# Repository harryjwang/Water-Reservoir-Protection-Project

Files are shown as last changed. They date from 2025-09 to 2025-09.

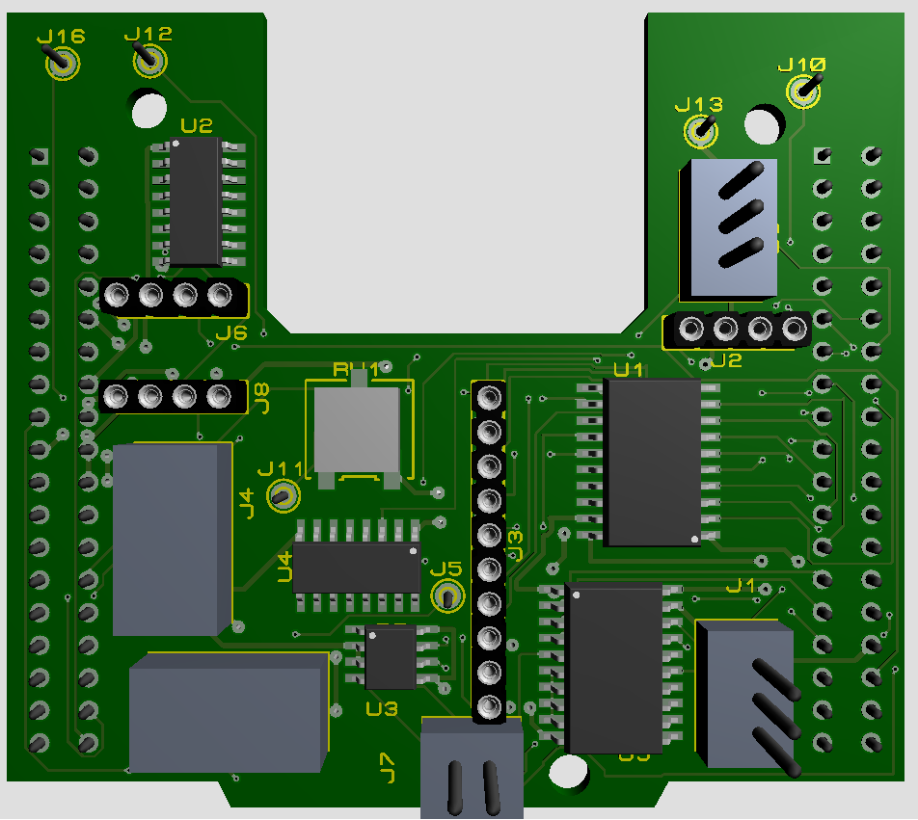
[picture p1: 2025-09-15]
Report Files/Top_View.png

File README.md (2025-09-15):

# Water-Reservoir-Protection-Project
Integrates multiple STM32 peripherals into a real-time water monitoring prototype:

- Ultrasonic sensor (HC-SR04): Determines water level.

- ADC1: Reads analog sensors (e.g., pressure/quality).

- Timers: Coordinate ultrasonic pulses and flow counting.

- UART: Reports water level + sensor readings.

- Clock: Tracks hours/minutes/seconds for timestamping.

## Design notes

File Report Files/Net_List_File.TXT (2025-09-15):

ISIS SCHEMATIC DESCRIPTION FORMAT 8.0
=====================================
Design:   ECE298_RS_ADAPTER
Doc. no.: <NONE>
Revision: <NONE>
Author:   <NONE>
Created:  11/11/2024
Modified: 12/3/2024

*PROPERTIES,0    

*MODELDEFS,0    

*PARTLIST,37   
C1,ECE298_RS_CAP_10U,100u,CODE="Digikey PCC2182TR-ND",EID=13,PACKAGE=CAPC2012X100
C2,ECE298_RS_CAP_10U,0.1u,CODE="Digikey PCC2182TR-ND",EID=7,PACKAGE=CAPC2012X100
C4,ECE298_RS_CAP_10U,100u,CODE="Digikey PCC2182TR-ND",EID=1B,PACKAGE=CAPC2012X100
C5,ECE298_RS_CAP_10U,10u,CODE="Digikey PCC2182TR-ND",EID=1C,PACKAGE=CAPC2012X100
C6,ECE298_RS_CAP_10U,0.1u,CODE="Digikey PCC2182TR-ND",EID=20,PACKAGE=CAPC2012X100
C7,ECE298_RS_CAP_10U,0.1u,CODE="Digikey PCC2182TR-ND",EID=B,PACKAGE=CAPC2012X100
C8,ECE298_RS_CAP_10U,100u,CODE="Digikey PCC2182TR-ND",EID=C,PACKAGE=CAPC2012X100
C9,ECE298_RS_CAP_10U,0.1u,CODE="Digikey PCC2182TR-ND",EID=23,PACKAGE=CAPC2012X100
C10,ECE298_RS_CAP_10U,10u,CODE="Digikey PCC2182TR-ND",EID=14,PACKAGE=CAPC2012X100
C12,ECE298_RS_CAP_10U,0.1u,CODE="Digikey PCC2182TR-ND",EID=2C,PACKAGE=CAPC2012X100
C13,ECE298_RS_CAP_10U,0.1u,CODE="Digikey PCC2182TR-ND",EID=2D,PACKAGE=CAPC2012X100
CN7,1-534236-9,1-534236-9,CODE=1-534236-9,EID=1,PACKAGE=ECE298_REVTRANS38DIL-1,SUPPLIER=TE_CONNECTIVITY
CN10,1-534236-9,1-534236-9,CODE=1-534236-9,EID=2,PACKAGE=ECE298_REVTRANS38DIL-1,SUPPLIER=TE_CONNECTIVITY
J1,ECE298_RS_3PINHDR,Servo,EID=3,PACKAGE=SIL-100-03
J2,ECE298_RS_4PINREC,"RGB LED",EID=4,PACKAGE=CONN-SIL4
J3,ECE298_RS_10PINREC,"Timer Board",EID=5,PACKAGE=CONN-SIL10
J4,ECE298_RS_BENCH_POWER,"Bench Power Supply",EID=F,PACKAGE=SIL-100-02R
J5,ECE298_TERMINAL_VIA,"Test Probe",EID=10,PACKAGE=PIN
J6,ECE298_RS_4PINREC,"RPM Sensor",EID=12,PACKAGE=CONN-SIL4
J7,ECE298_RS_2PINHDR,"Brush Motor",EID=11,PACKAGE=SIL-100-02
J8,ECE298_RS_4PINREC,"HC-SR04 Distance Sensor",EID=19,PACKAGE=CONN-SIL4
J9,ECE298_RS_3PINHDR,"USART Connector",EID=1E,PACKAGE=SIL-100-03
J10,ECE298_TERMINAL_VIA,"Test Probe",EID=25,PACKAGE=PIN
J11,ECE298_TERMINAL_VIA,"Test Probe",EID=27,PACKAGE=PIN
J12,ECE298_TERMINAL_VIA,"Test Probe",EID=29,PACKAGE=PIN
J13,ECE298_TERMINAL_VIA,"Test Probe",EID=2A,PACKAGE=PIN
J15,ECE298_RS_BENCH_POWER,"Bench Power Supply",EID=1A,PACKAGE=SIL-100-02R
J16,ECE298_TERMINAL_VIA,"Test Probe",EID=8,PACKAGE=PIN
R1,9C04021A1500JLHF3,150,CODE="Digikey 311-150JDKR-ND",EID=15,PACKAGE=RESC1005X40,PRIMTYPE=RESISTOR
R2,9C04021A1800JLHF3,80,CODE="Digikey 311-180JCT-ND",EID=16,PACKAGE=RESC1005X40,PRIMTYPE=RESISTOR
R3,9C04021A2000JLHF3,80,CODE="Digikey 311-200JCT-ND",EID=17,PACKAGE=RESC1005X40,PRIMTYPE=RESISTOR
R4,9C04021A2400JLHF3,1K,CODE="Digikey 311-240JCT-ND",EID=18,PACKAGE=RESC1005X40,PRIMTYPE=RESISTOR
RV1,ECE298_RS_POT10K,10K,CODE="Digikey 3361P-103GLFDKR-ND",EID=E,PACKAGE=TRIM_3361P,STATE=5
U1,ECE298_RS_74HCT541,ECE298_RS_74HCT541,EID=6,GND=GND,PACKAGE=SO20W,PINSWAP="1,19",VCC=+5.0V
U2,ECE298_RS_CMOS4050,ECE298_RS_CMOS4050,EID_A=9,EID_B=A,EID_C=1D,EID_D=21,EID_E=22,EID_F=24,ITFMOD=CMOS,MODFILE=40BUF,PACKAGE=SO16,VDD=+3.3V,VSS=GND
U3,ECE298_RS_L9110,"Motor Controller (L9110)",EID=D,ITFMOD=TTL,PACKAGE=SO8
U5,ECE298_RS_74HCT541,ECE298_RS_74HCT541,EID=1F,GND=GND,PACKAGE=SO20W,PINSWAP="1,19",VCC=+5.0V

*NETLIST,73   
#00076,3,CLASS=SIGNAL
J1,PS,1
U5,TS,15
J5,PS,1

#00081,2,CLASS=POWER
U3,OP,1
J7,PS,1

#00082,2,CLASS=POWER
U3,OP,4
J7,PS,2

#00090,2,CLASS=SIGNAL
R2,PS,1
U5,TS,18

#00091,3,CLASS=SIGNAL
R2,PS,2
J10,PS,1
J2,PS,1

#00093,5,CLASS=SIGNAL
R4,PS,2
U5,IP,9
U5,IP,6
U5,IP,7
U5,IP,8

#00103,2,CLASS=SIGNAL
J8,PS,3
U2,IP,3

#00109,2,CLASS=SIGNAL
J9,PS,3
U2,IP,5

#00110,2,CLASS=SIGNAL
J2,PS,2
R1,PS,2

#00112,2,CLASS=SIGNAL
J2,PS,4
R3,PS,2

#00113,2,CLASS=SIGNAL
R1,PS,1
U5,TS,17

#00114,2,CLASS=SIGNAL
R3,PS,1
U5,TS,16

#00121,3,CLASS=SIGNAL
J12,PS,1
U1,TS,18
J3,PS,1

#00133,2,CLASS=SIGNAL
U1,TS,17
J3,PS,2

#00134,2,CLASS=SIGNAL
U1,TS,16
J3,PS,3

#00135,2,CLASS=SIGNAL
U1,TS,15
J3,PS,4

#00136,2,CLASS=SIGNAL
U1,TS,14
J3,PS,5

#00137,2,CLASS=SIGNAL
U1,TS,13
J3,PS,6

#00138,2,CLASS=SIGNAL
U1,TS,12
J3,PS,7

#00139,2,CLASS=SIGNAL
U1,TS,11
J3,PS,8

PC10,2
PC10,GT
CN7,PS,1

PC11,2
PC11,GT
CN7,PS,2

PB7,2
PB7,GT
CN7,PS,21

PC12,2
PC12,GT
CN7,PS,3

PA1,2
PA1,GT
CN7,PS,30

PA4,2
PA4,GT
CN7,PS,32

PB0,2
PB0,GT
CN7,PS,34

PC2,2
PC2,GT
CN7,PS,35

PC3,2
PC3,GT
CN7,PS,37

PC9,2
PC9,GT
CN10,PS,1

PB12,2
PB12,GT
CN10,PS,16

PC8,2
PC8,GT
CN10,PS,2

PB2,2
PB2,GT
CN10,PS,22

PB1,2
PB1,GT
CN10,PS,24

PB15,2
PB15,GT
CN10,PS,26

PB8,2
PB8,GT
CN10,PS,3

PA10,2
PA10,GT
CN10,PS,33

PC6,2
PC6,GT
CN10,PS,4

PB9,2
PB9,GT
CN10,PS,5

PC5,2
PC5,GT
CN10,PS,6

PA13,2
PA13,GT
CN7,PS,13

PA14,2
PA14,GT
CN7,PS,15

PC13,2
PC13,GT
CN7,PS,23

PB11,2
PB11,GT
CN10,PS,18

PA2,2
PA2,GT
CN10,PS,35

PA3,2
PA3,GT
CN10,PS,37

MOTOR_CONTROL_PWM_1 (PB_14),3,CLASS=SIGNAL
MOTOR_CONTROL_PWM_1 (PB_14),GT
U3,IP,6
CN10,PS,28

MOTOR_CONTROL_PWM_2 (PB_13),3,CLASS=SIGNAL
MOTOR_CONTROL_PWM_2 (PB_13),GT
U3,IP,7
CN10,PS,30

POTENTIOMETER_ADC (PA_0),4,CLASS=SIGNAL
POTENTIOMETER_ADC (PA_0),GT
RV1,PS,3
J11,PS,1
CN7,PS,28

RPM_D0_PIN (PC_4),3,CLASS=SIGNAL
RPM_D0_PIN (PC_4),GT
J6,PS,3
CN10,PS,34

DISTANCE_TRIG_INPUT (PC_1),3,CLASS=SIGNAL
DISTANCE_TRIG_INPUT (PC_1),GT
J8,PS,2
CN7,PS,36

NUCLEO_TO_USART (PA_11),3,CLASS=SIGNAL
NUCLEO_TO_USART (PA_11),GT
J9,PS,2
CN10,PS,14

USART_TO_NUCLEO (PA_12),3,CLASS=SIGNAL
USART_TO_NUCLEO (PA_12),GT
U2,OP,4
CN10,PS,12

SERVO_PWM_PIN (PA_15),3,CLASS=SIGNAL
SERVO_PWM_PIN (PA_15),GT
U5,IP,5
CN7,PS,17

DISTANCE_ECHO_OUTPUT (PC_0),4,CLASS=SIGNAL
DISTANCE_ECHO_OUTPUT (PC_0),GT
J16,PS,1
U2,OP,2
CN7,PS,38

SEVEN_SEG_D0_IN (PA_5),3,CLASS=SIGNAL
SEVEN_SEG_D0_IN (PA_5),GT
U1,IP,2
CN10,PS,11

SEVEN_SEG_D1_IN (PA_6),3,CLASS=SIGNAL
SEVEN_SEG_D1_IN (PA_6),GT
U1,IP,3
CN10,PS,13

SEVEN_SEG_D2_IN (PA_7),3,CLASS=SIGNAL
SEVEN_SEG_D2_IN (PA_7),GT
U1,IP,4
CN10,PS,15

SEVEN_SEG_D3_IN (PB_6),3,CLASS=SIGNAL
SEVEN_SEG_D3_IN (PB_6),GT
U1,IP,5
CN10,PS,17

SEVEN_SEG_D4_IN (PC_7),3,CLASS=SIGNAL
SEVEN_SEG_D4_IN (PC_7),GT
U1,IP,6
CN10,PS,19

SEVEN_SEG_D5_IN (PA_9),3,CLASS=SIGNAL
SEVEN_SEG_D5_IN (PA_9),GT
U1,IP,7
CN10,PS,21

SEVEN_SEG_D6_IN (PA_8),3,CLASS=SIGNAL
SEVEN_SEG_D6_IN (PA_8),GT
U1,IP,8
CN10,PS,23

SEVEN_SEG_D7_IN (PB_10),3,CLASS=SIGNAL
SEVEN_SEG_D7_IN (PB_10),GT
U1,IP,9
CN10,PS,25

RED_LED_PIN (PB_4),3,CLASS=SIGNAL
RED_LED_PIN (PB_4),GT
U5,IP,2
CN10,PS,27

GREEN_LED_PIN (PB_5),3,CLASS=SIGNAL
GREEN_LED_PIN (PB_5),GT
U5,IP,3
CN10,PS,29

BLUE_LED_PIN (PB_3),3,CLASS=SIGNAL
BLUE_LED_PIN (PB_3),GT
U5,IP,4
CN10,PS,31

{NC},31,CLASS=SIGNAL
U2,PS,13
U2,PS,16
U2,OP,15
U2,OP,12
U2,OP,10
U2,OP,6
U5,TS,11
U5,TS,12
U5,TS,13
U5,TS,14
J6,PS,4
CN7,PS,14
CN10,PS,8
CN10,PS,7
CN10,PS,38
CN10,PS,36
CN10,PS,10
CN7,PS,9
CN7,PS,7
CN7,PS,6
CN7,PS,5
CN7,PS,4
CN7,PS,33
CN7,PS,31
CN7,PS,29
CN7,PS,27
CN7,PS,26
CN7,PS,25
CN7,PS,24
CN7,PS,11
CN7,PS,10

+3.3V,11,CLASS=POWER
+3.3V,PR
VCC,LBL
U2,PP,1
C7,PS,1
C2,PS,1
C4,PS,1
J6,PS,1
C1,PS,1
RV1,PS,2
CN7,PS,16
CN7,PS,12

+5.0V,9,CLASS=POWER
+5.0V,PR
U5,PP,20
C8,PS,1
J3,PS,9
C13,PS,1
C12,PS,1
U1,PP,20
J8,PS,1
CN7,PS,18

+5.0V_EXT,2,CLASS=POWER
+5.0V_EXT,PR
J1,PS,2

+5V_EXT,3,CLASS=POWER
+5V_EXT,PR
J15,PS,1
C10,PS,1

+6V_EXT,7,CLASS=POWER
+6V_EXT,PR
C9,PS,1
C6,PS,1
J4,PS,1
C5,PS,1
U3,PP,2
U3,PP,3

GND,43,CLASS=POWER
GND,PR
U2,PP,8
U2,IP,9
U2,IP,11
U2,IP,7
U2,IP,14
U5,PP,10
J15,PS,2
C10,PS,2
C8,PS,2
J13,PS,1
C7,PS,2
C2,PS,2
C6,PS,2
C13,PS,2
C12,PS,2
U1,PP,10
C9,PS,2
U1,IP,1
U1,IP,19
J2,PS,3
J9,PS,1
J3,PS,10
J8,PS,4
J6,PS,2
J4,PS,2
C5,PS,2
R4,PS,1
U5,IP,1
U5,IP,19
C1,PS,2
RV1,PS,1
U3,PP,5
U3,PP,8
J1,PS,3
CN10,PS,9
CN10,PS,32
CN10,PS,20
C4,PS,2
CN7,PS,8
CN7,PS,22
CN7,PS,20
CN7,PS,19

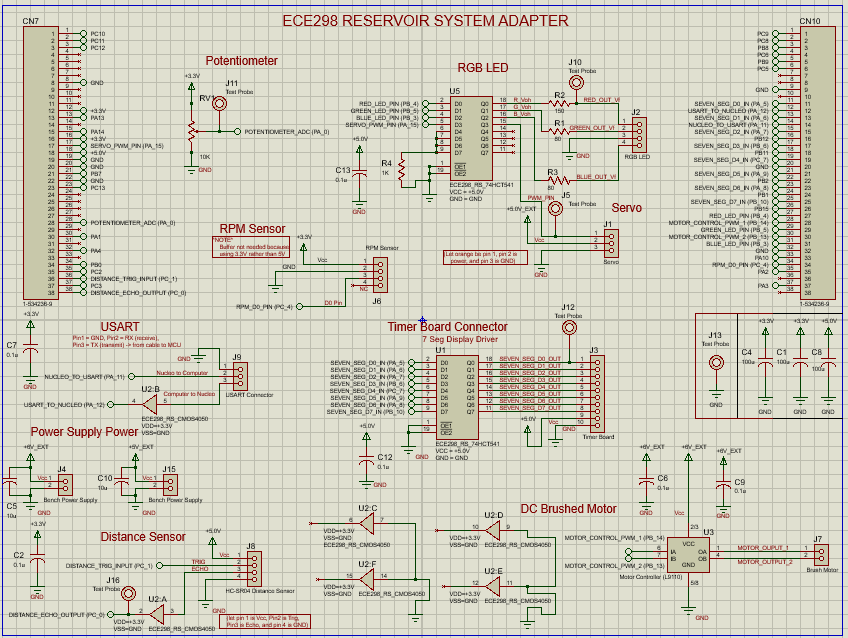
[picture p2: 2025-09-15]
Report Files/Final Schematic.PNG

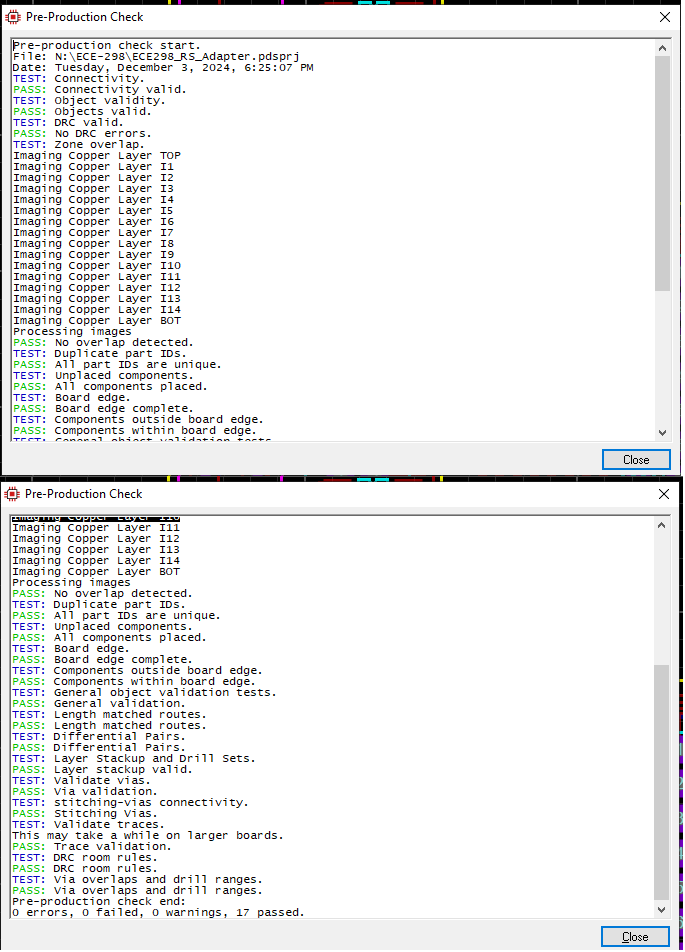
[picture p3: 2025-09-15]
Report Files/Pre_Production_Checklist.png

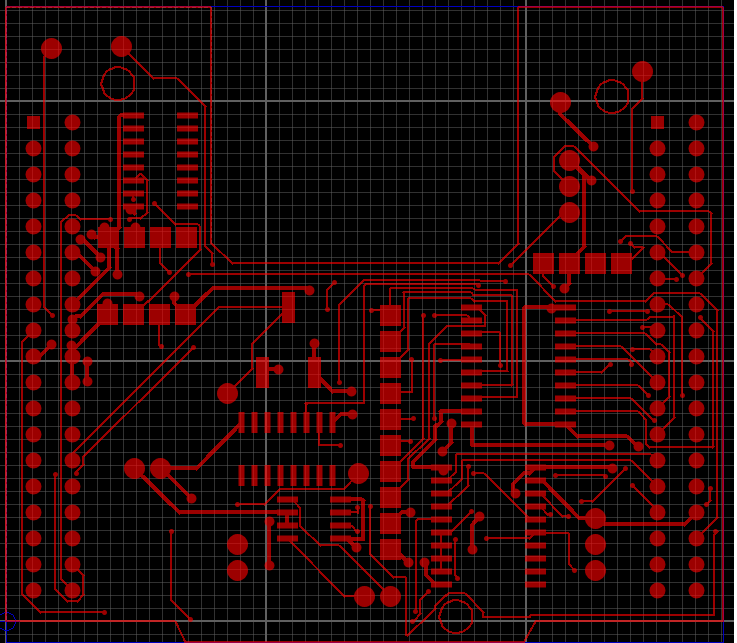
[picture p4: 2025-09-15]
Report Files/Top_Copper_Layer.png

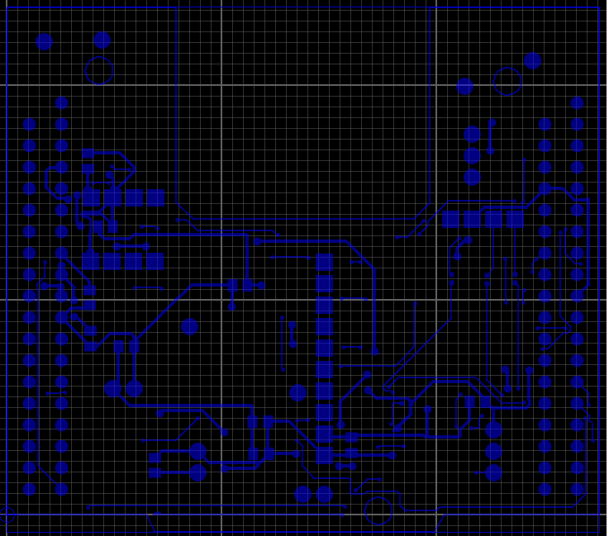
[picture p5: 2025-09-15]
Report Files/Bottom_Copper_Layer.png

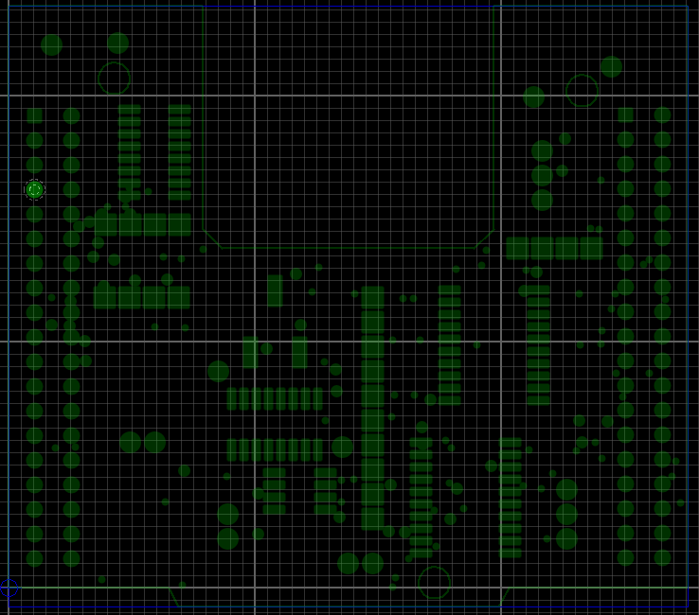
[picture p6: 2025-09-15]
Report Files/Top_Resistor_Layer.png

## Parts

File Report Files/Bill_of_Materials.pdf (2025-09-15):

## Bill Of Materials for ECE298_RS_ADAPTER

Design Title | ECE298_RS_ADAPTER

### Author Document Number Revision

Design Created | Monday, November 11, 2024
Design Last Modified Monday, November 11, 2024

### Total Parts In Design 38

0 Modules
Quantity | References | Value
Sub-totals:
11 Capacitors
Quantity | References | Value
3 | C1,C4,C8 | 100u
6 | C2,C6-C7,C9,C12-C13 | 0.1u
2 | C5,C10 | 10u
Sub-totals:
4 Resistors
Quantity | References | Value
1 | R1 | 150
2 | R2-R3 | 80
1 | R4 | 1K
Sub-totals:
5 Integrated Circuits
Quantity | References | Value
2 | U1,U5 | ECE298_RS_74HCT541
2 | U2,U4 | ECE298_RS_CMOS4050
1 | U3 | Motor Controller (L9110)
Sub-totals:
0 Transistors
Quantity | References | Value
Sub-totals:
0 Diodes
Quantity | References | Value
Sub-totals:
18 Miscellaneous
Quantity | References | Value
2 | CN7,CN10 | 1-534236-9
1 | J1 | Servo
1 | J2 | RGB LED
1 | J3 | Timer Board
2 | J4,J15 | Bench Power Supply
6 | J5,J10-J13,J16 | Test Probe
1 | J6 | RPM Sensor
1 | J7 | Brush Motor
1 | J8 | HC-SR04 Distance Sensor
1 | J9 | USARTConnector
1 | RV1 | 10K
Sub-totals:

Totals:

| | Tuesday, December 3, 2024 6:30:23 PM

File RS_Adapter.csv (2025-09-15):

Part ID | Value | Package | Stock Code | Layer | Rotation | X | Y
CN7 | 1-534236-9 | ECE298_REVTRANS38DIL-1 | 1-534236-9 | BOT | 0 | 177.362 | 1019.69
CN10 | 1-534236-9 | ECE298_REVTRANS38DIL-1 | 1-534236-9 | BOT | 0 | 2577.36 | 1021.26
J2 | RGB LED | CONN-SIL4 |  | TOP | 180 | 2213.78 | 1377.95
J3 | Timer Board | CONN-SIL10 |  | TOP | 270 | 1476.38 | 729.528
J4 | Bench Power Supply | SIL-100-02R |  | TOP | 0 | 542.126 | 590.551
J6 | RPM Sensor | CONN-SIL4 |  | TOP | 0 | 542.126 | 1476.38
J8 | HC-SR04 Distance Sensor | CONN-SIL4 |  | TOP | 180 | 538.976 | 1181.1
J9 | USART Connector | SIL-100-03 |  | TOP | 270 | 2165.35 | 1674.8
J7 | Brush Motor | SIL-100-02 |  | TOP | 180 | 1426.38 | 98.4252
J15 | Bench Power Supply | SIL-100-02R |  | TOP | 90 | 887.402 | 246.85
U1 | ECE298_RS_74HCT541 | SO20W |  | TOP | -180 | 1968.5 | 984.252
U2 | ECE298_RS_CMOS4050 | SO16 |  | TOP | 0 | 590.551 | 1771.65
U3 | Motor Controller (L9110) | SO8 |  | TOP | 0 | 1181.1 | 393.701
U4 | ECE298_RS_CMOS4050 | SO16 |  | TOP | 270 | 1078.6 | 663.976
U5 | ECE298_RS_74HCT541 | SO20W |  | TOP | 0 | 1853.23 | 367.126
J1 | Servo | SIL-100-03 |  | TOP | 90 | 2263.78 | 296.85
RV1 | 10K | TRIM_3361P | Digikey 3361P-103GLFDKR-ND | TOP | 0 | 1082.68 | 1082.68
R1 | 150 | RESC1005X40 | Digikey 311-150JDKR-ND | BOT | -90 | 2232.28 | 1098.43
R2 | 80 | RESC1005X40 | Digikey 311-180JCT-ND | BOT | -90 | 2362.2 | 1102.36
R3 | 80 | RESC1005X40 | Digikey 311-200JCT-ND | BOT | -90 | 2066.93 | 1102.36
C5 | 10u | CAPC2012X100 | Digikey PCC2182TR-ND | BOT | 180 | 555.118 | 787.402
C10 | 10u | CAPC2012X100 | Digikey PCC2182TR-ND | BOT | -90 | 688.976 | 232.283
C2 | 0.1u | CAPC2012X100 | Digikey PCC2182TR-ND | BOT | 180 | 456.693 | 1342.52
C1 | 100u | CAPC2012X100 | Digikey PCC2182TR-ND | BOT | 270 | 374.016 | 1649.61
R4 | 1K | RESC1005X40 | Digikey 311-240JCT-ND | BOT | 0 | 1858.27 | 519.685
C9 | 0.1u | CAPC2012X100 | Digikey PCC2182TR-ND | BOT | -180 | 1177.17 | 437.008
C6 | 0.1u | CAPC2012X100 | Digikey PCC2182TR-ND | BOT | 180 | 1181.1 | 287.402
C7 | 0.1u | CAPC2012X100 | Digikey PCC2182TR-ND | BOT | 0 | 1082.68 | 1070.87
C4 | 100u | CAPC2012X100 | Digikey PCC2182TR-ND | BOT | 90 | 381.89 | 1011.81
C8 | 100u | CAPC2012X100 | Digikey PCC2182TR-ND | BOT | 90 | 385.827 | 822.835
C12 | 0.1u | CAPC2012X100 | Digikey PCC2182TR-ND | BOT | 90 | 1602.36 | 326.772
C13 | 0.1u | CAPC2012X100 | Digikey PCC2182TR-ND | BOT | 180 | 2188.98 | 527.559
J5 | Test Probe | PIN |  | TOP | 0 | 1354.33 | 570.866
J11 | Test Probe | PIN |  | TOP | 0 | 850.394 | 877.953
J13 | Test Probe | PIN |  | TOP | 0 | 2129.92 | 1996.06
J10 | Test Probe | PIN |  | TOP | 0 | 2444.88 | 2118.11
J12 | Test Probe | PIN |  | TOP | 0 | 440.945 | 2212.6
J16 | Test Probe | PIN |  | TOP | 0 | 173.228 | 2204.72

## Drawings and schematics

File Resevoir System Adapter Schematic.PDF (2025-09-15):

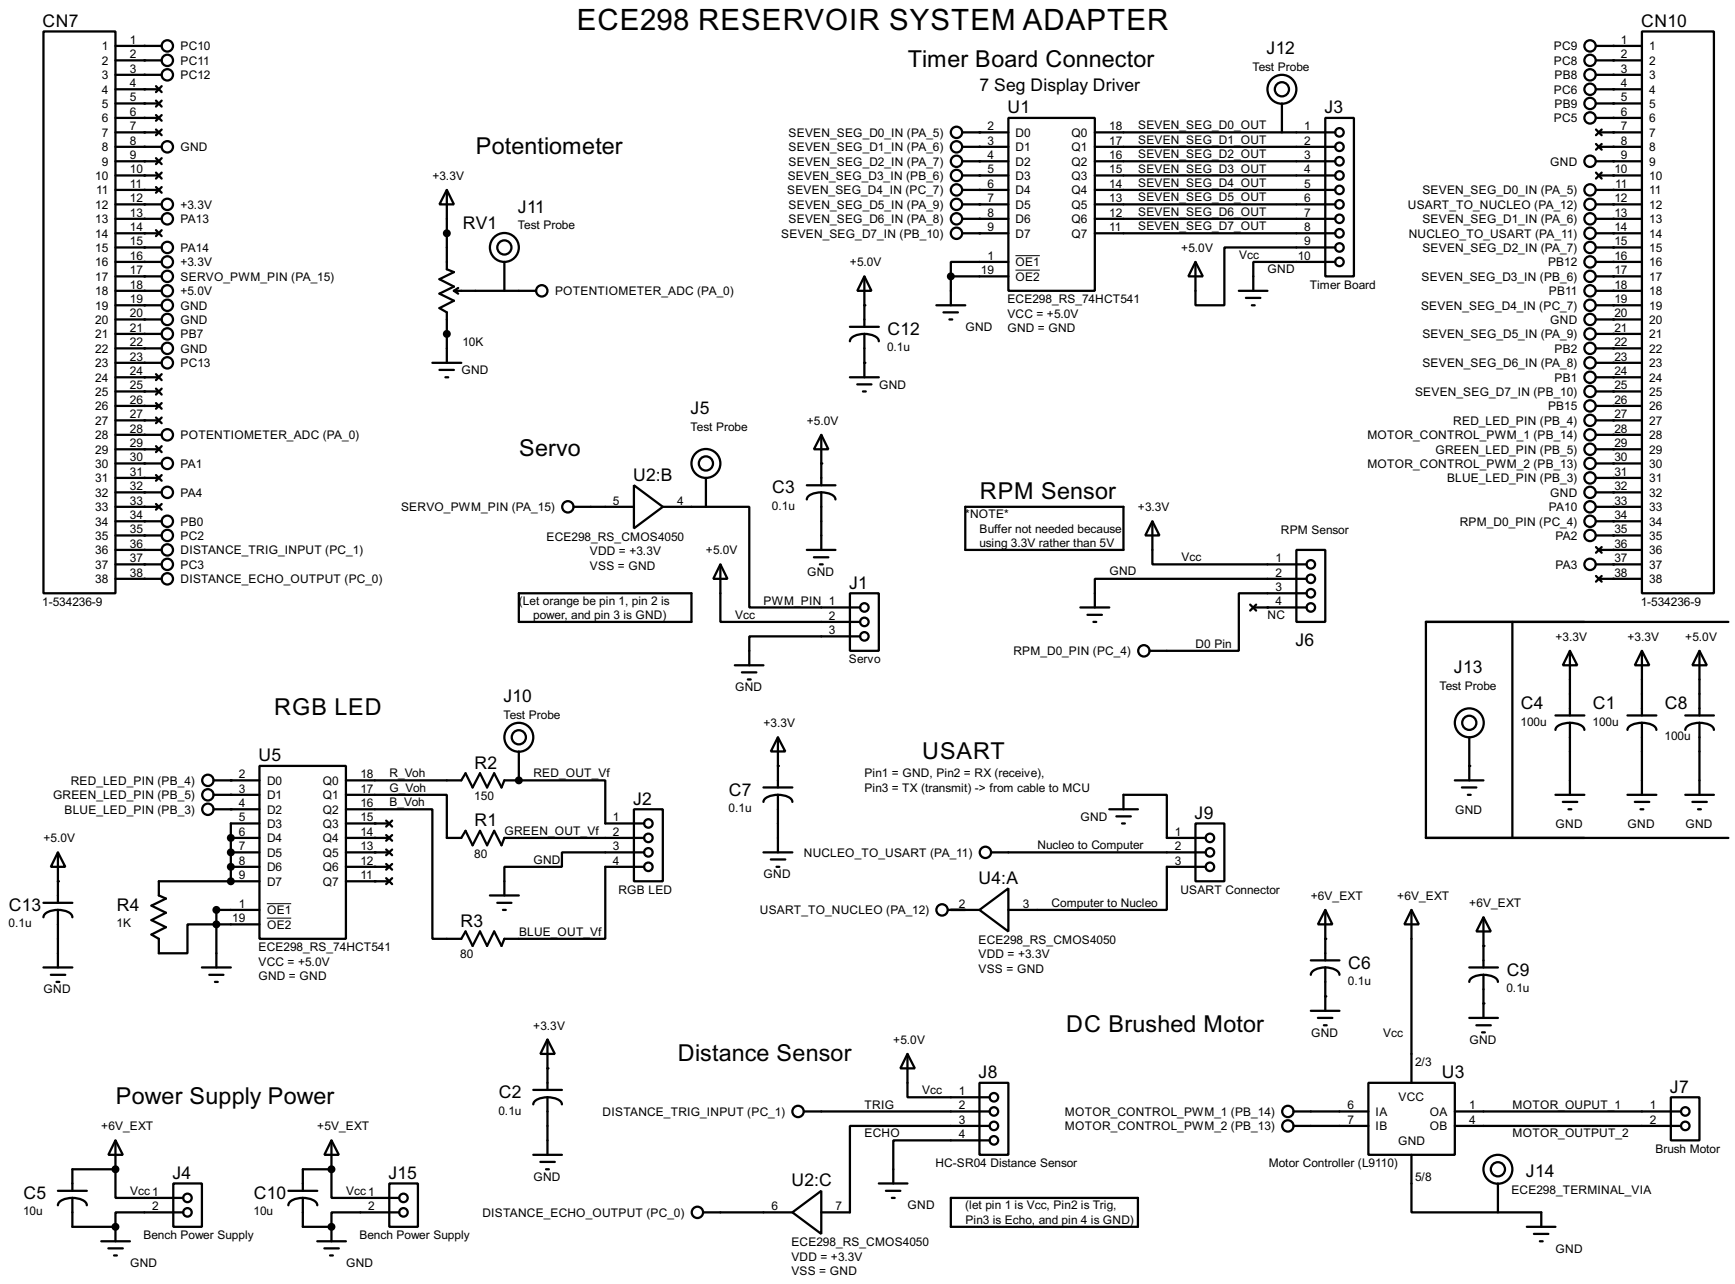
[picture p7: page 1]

*NOTE* Buffer not needed because

(Let orange be pin 1, pin 2 is
power, and pin 3 is GND)

Pin3 = TX (transmit) -> from cable to MCU

(let pin 1 is Vcc, Pin2 is Trig,
Pin3 is Echo, and pin 4 is GND)

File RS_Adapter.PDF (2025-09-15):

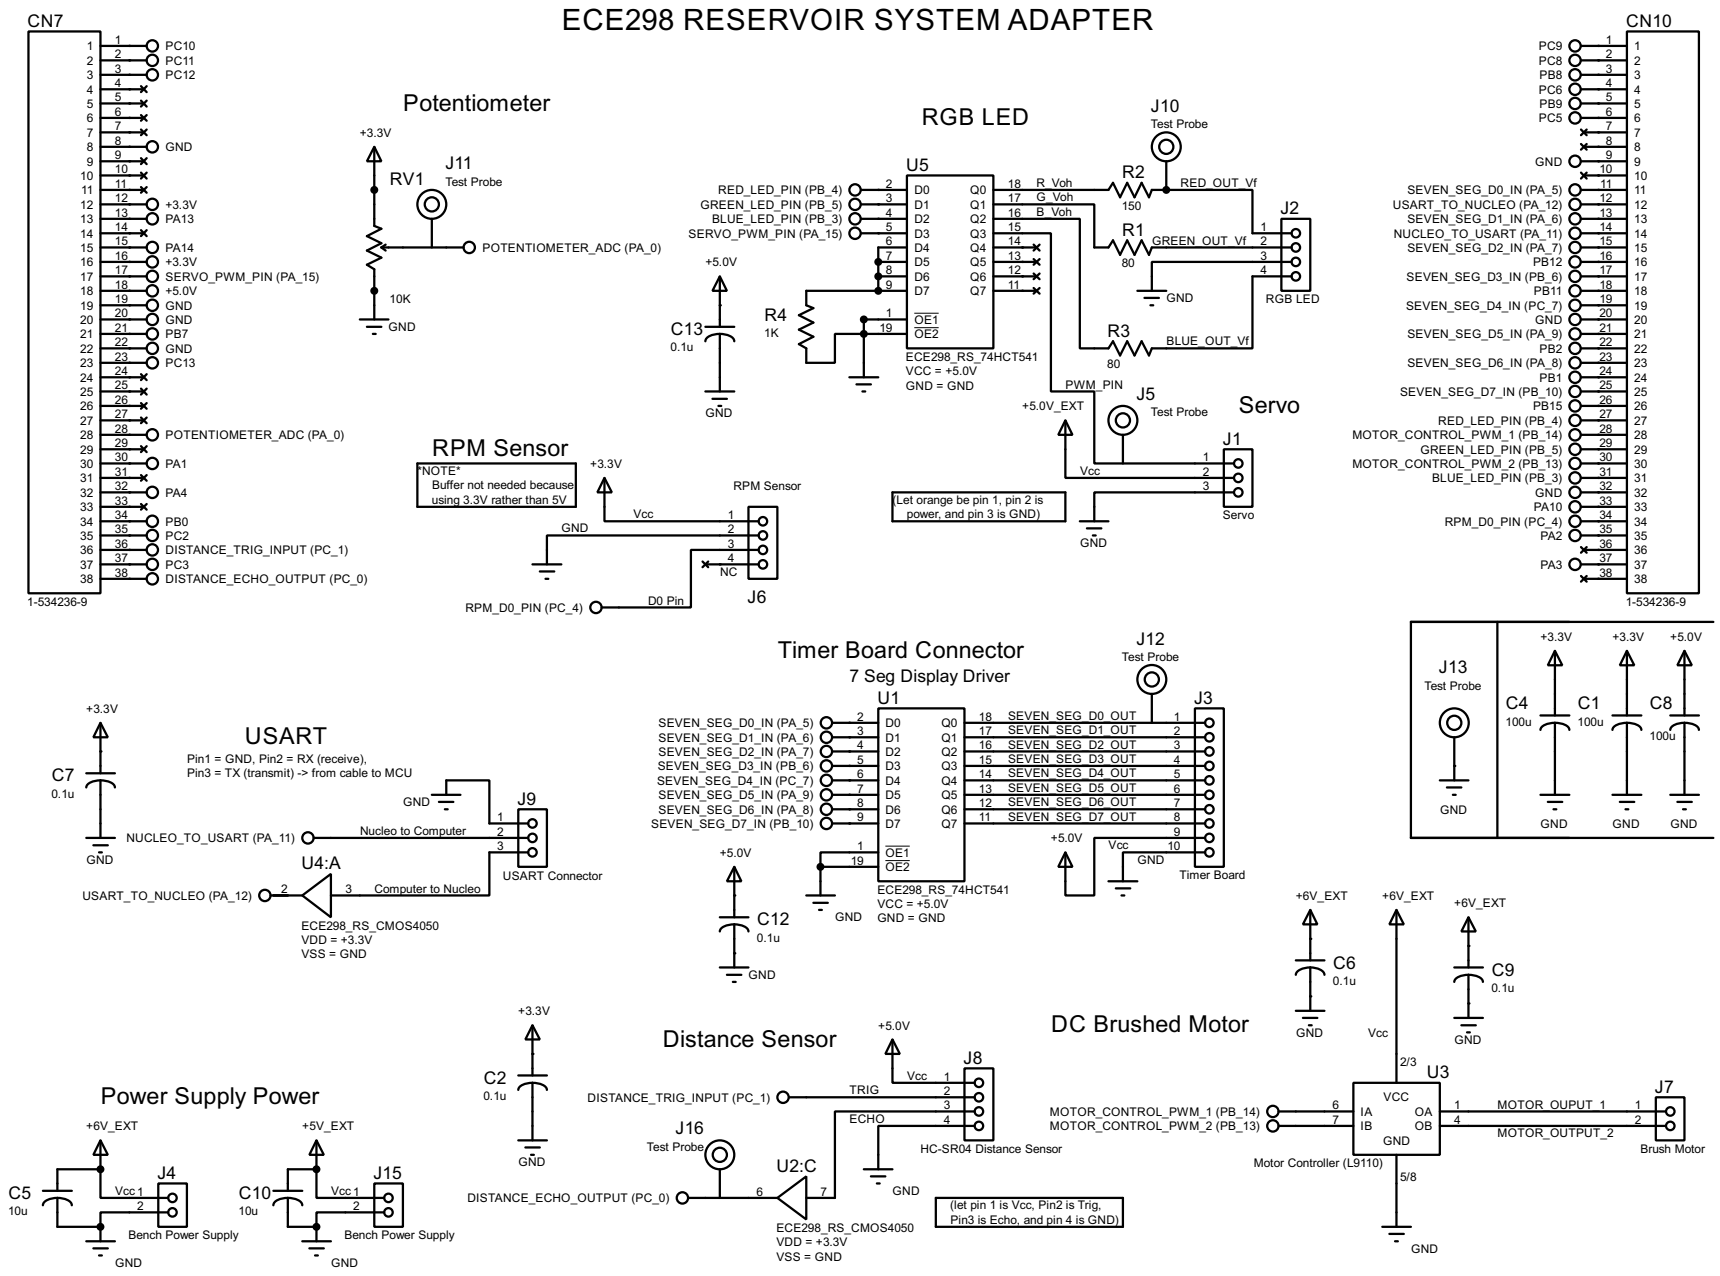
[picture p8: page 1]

*NOTE* Buffer not needed because

(Let orange be pin 1, pin 2 is
power, and pin 3 is GND)

Pin1 = GND, Pin2 = RX (receive),
Pin3 = TX (transmit) -> from cable to MCU

(let pin 1 is Vcc, Pin2 is Trig,
Pin3 is Echo, and pin 4 is GND)

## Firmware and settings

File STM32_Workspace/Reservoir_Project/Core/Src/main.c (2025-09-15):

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
/* Includes ------------------------------------------------------------------*/
#include "main.h"
#include <string.h>
#include <stdio.h>
uint8_t txd_message_buffer[64] = {0};
uint8_t rpm_tick_count = 0;
ADC_HandleTypeDef hadc1;

TIM_HandleTypeDef htim1;
TIM_HandleTypeDef htim3;

UART_HandleTypeDef huart2;
UART_HandleTypeDef huart6;

/* USER CODE BEGIN PV */
uint8_t wall_clock_hr_update_flag = 0;
volatile uint8_t clock_hours = 0;
volatile uint8_t clock_mins = 0;
volatile uint8_t clock_secs = 0;
volatile uint8_t distance = 0;
/* USER CODE END PV */

void SystemClock_Config(void);
static void MX_GPIO_Init(void);
static void MX_USART2_UART_Init(void);
static void MX_ADC1_Init(void);
static void MX_TIM1_Init(void);
static void MX_TIM3_Init(void);
static void MX_USART6_UART_Init(void);
/* USER CODE BEGIN 0 */
volatile uint8_t hcsr04_Rx_flag = 0;
volatile uint32_t first_edge = 0;
volatile uint32_t time_edge1 = 0;
volatile uint32_t time_edge2 = 0;
volatile uint32_t time_diff = 0;

void ADC_Select_CH(int CH)
{
ADC_ChannelConfTypeDef sConfig = {0};
switch(CH)
{
case 0:
sConfig.Channel = ADC_CHANNEL_0;
sConfig.Rank = 1;
if (HAL_ADC_ConfigChannel(&hadc1, &sConfig) != HAL_OK)
{
Error_Handler();
}
break;
case 1:
sConfig.Channel = ADC_CHANNEL_1;
sConfig.Rank = 1;
if (HAL_ADC_ConfigChannel(&hadc1, &sConfig) != HAL_OK)
{
Error_Handler();
}
break;
case 2:
sConfig.Channel = ADC_CHANNEL_2;
sConfig.Rank = 1;
if (HAL_ADC_ConfigChannel(&hadc1, &sConfig) != HAL_OK)
{
Error_Handler();
}
break;
case 3:
sConfig.Channel = ADC_CHANNEL_3;
sConfig.Rank = 1;
if (HAL_ADC_ConfigChannel(&hadc1, &sConfig) != HAL_OK)
{
Error_Handler();
}
break;
case 4:
sConfig.Channel = ADC_CHANNEL_4;
sConfig.Rank = 1;
if (HAL_ADC_ConfigChannel(&hadc1, &sConfig) != HAL_OK)
{
Error_Handler();
}
break;
case 5:
sConfig.Channel = ADC_CHANNEL_5;
sConfig.Rank = 1;
if (HAL_ADC_ConfigChannel(&hadc1, &sConfig) != HAL_OK)
{
Error_Handler();
}
break;
case 6:
sConfig.Channel = ADC_CHANNEL_6;
sConfig.Rank = 1;
if (HAL_ADC_ConfigChannel(&hadc1, &sConfig) != HAL_OK)
{
Error_Handler();
}
break;
case 7:
sConfig.Channel = ADC_CHANNEL_7;
sConfig.Rank = 1;
if (HAL_ADC_ConfigChannel(&hadc1, &sConfig) != HAL_OK)
{
Error_Handler();
}
break;
case 8:
sConfig.Channel = ADC_CHANNEL_8;
sConfig.Rank = 1;
if (HAL_ADC_ConfigChannel(&hadc1, &sConfig) != HAL_OK)
{
Error_Handler();
}
break;
case 9:
sConfig.Channel = ADC_CHANNEL_9;
sConfig.Rank = 1;
if (HAL_ADC_ConfigChannel(&hadc1, &sConfig) != HAL_OK)
{
Error_Handler();
}
break;
case 10:
sConfig.Channel = ADC_CHANNEL_10;
sConfig.Rank = 1;
if (HAL_ADC_ConfigChannel(&hadc1, &sConfig) != HAL_OK)
{
Error_Handler();
}
break;
case 11:
sConfig.Channel = ADC_CHANNEL_11;
sConfig.Rank = 1;
if (HAL_ADC_ConfigChannel(&hadc1, &sConfig) != HAL_OK)
{
Error_Handler();
}
break;
case 12:
sConfig.Channel = ADC_CHANNEL_12;
sConfig.Rank = 1;
if (HAL_ADC_ConfigChannel(&hadc1, &sConfig) != HAL_OK)
{
Error_Handler();
}
break;
case 13:
sConfig.Channel = ADC_CHANNEL_13;
sConfig.Rank = 1;
if (HAL_ADC_ConfigChannel(&hadc1, &sConfig) != HAL_OK)
{
Error_Handler();
}
break;
case 14:
sConfig.Channel = ADC_CHANNEL_14;
sConfig.Rank = 1;
if (HAL_ADC_ConfigChannel(&hadc1, &sConfig) != HAL_OK)
{
Error_Handler();
}
break;
case 15:
sConfig.Channel = ADC_CHANNEL_15;
sConfig.Rank = 1;
if (HAL_ADC_ConfigChannel(&hadc1, &sConfig) != HAL_OK)
{
Error_Handler();
}
break;
}
}
/* USER CODE END 0 */

/**
  * @brief  The application entry point.
  * @retval int
  */
int main(void)
{

  /* USER CODE BEGIN 1 */

	//distance sensor pulse sending
	void HCSR04_TRIG_PULSE(void){
		HAL_GPIO_WritePin(GPIOC, TRIG_PIN_Pin, GPIO_PIN_SET);
		for(int j=0; j!=48; j= j+1){};
		HAL_GPIO_WritePin(GPIOC, TRIG_PIN_Pin, GPIO_PIN_RESET);
		HAL_Delay(30);
	}

	// printing digits A and B
	void DIGITS_Display(uint8_t DIGIT_A, uint8_t DIGIT_B)
		{
			 uint8_t DIGITA_VAL = 0x0F & DIGIT_A; //mask off higher4 bits
			 int Abit0 = (DIGITA_VAL ) & 1;  	// extract Abit0 of the 4-bit value
			 int Abit1 = (DIGITA_VAL >> 1) & 1;  // extract Abit1 of the 4-bit value
			 int Abit2 = (DIGITA_VAL >> 2) & 1;  // extract Abit2 of the 4-bit value
			 int Abit3 = (DIGITA_VAL >> 3) & 1;  // extract Abit3 of the 4-bit value

			 uint8_t DIGITB_VAL = 0x0F & DIGIT_B; //mask off higher4 bits
			 int Bbit0 = (DIGITB_VAL ) & 1;  	// extract Bbit0 of the 4-bit value
			 int Bbit1 = (DIGITB_VAL >> 1) & 1;  // extract Bbit1 of the 4-bit value
			 int Bbit2 = (DIGITB_VAL >> 2) & 1;  // extract Bbit2 of the 4-bit value
			 int Bbit3 = (DIGITB_VAL >> 3) & 1;  // extract Bbit3 of the 4-bit value

			 if (Abit0 == (0))
			 {
				 HAL_GPIO_WritePin(GPIOB, DIGIT_A0_Pin, GPIO_PIN_RESET);
			 }
			 else
			 {
				 HAL_GPIO_WritePin(GPIOB, DIGIT_A0_Pin, GPIO_PIN_SET);
			 }
			 if (Abit1 == (0))
			 {
				 HAL_GPIO_WritePin(GPIOA, DIGIT_A1_Pin, GPIO_PIN_RESET);
			 }
			 else
			 {
				 HAL_GPIO_WritePin(GPIOA, DIGIT_A1_Pin, GPIO_PIN_SET);
			 }
			 if (Abit2 == (0))
			 {
				 HAL_GPIO_WritePin(GPIOA, DIGIT_A2_Pin, GPIO_PIN_RESET);
			 }
			 else
			 {
				 HAL_GPIO_WritePin(GPIOA, DIGIT_A2_Pin, GPIO_PIN_SET);
			 }
			 if (Abit3 == (0))
			 {
				 HAL_GPIO_WritePin(GPIOA, DIGIT_A3_Pin, GPIO_PIN_RESET);
			 }
			 else
			 {
				 HAL_GPIO_WritePin(GPIOA, DIGIT_A3_Pin, GPIO_PIN_SET);
			 }
			 if (Bbit0 == (0))
			 {
				 HAL_GPIO_WritePin(GPIOB, DIGIT_B0_Pin, GPIO_PIN_RESET);
			 }
			 else
			 {
				 HAL_GPIO_WritePin(GPIOB, DIGIT_B0_Pin, GPIO_PIN_SET);
			 }
			 if (Bbit1 == (0))
			 {
				 HAL_GPIO_WritePin(GPIOB, DIGIT_B1_Pin, GPIO_PIN_RESET);
			 }
			 else
			 {
				 HAL_GPIO_WritePin(GPIOB, DIGIT_B1_Pin, GPIO_PIN_SET);

			 }
			 if (Bbit2 == (0))
			 {
				 HAL_GPIO_WritePin(GPIOC, DIGIT_B2_Pin, GPIO_PIN_RESET);
			 }
			 else
			 {
				 HAL_GPIO_WritePin(GPIOC, DIGIT_B2_Pin, GPIO_PIN_SET);
			 }
			 if (Bbit3 == (0))
			 {
				 HAL_GPIO_WritePin(GPIOC, DIGIT_B3_Pin, GPIO_PIN_RESET);
			 }
			 else
			 {
				 HAL_GPIO_WritePin(GPIOC, DIGIT_B3_Pin, GPIO_PIN_SET);
			 }
		}


  /* USER CODE END 1 */

  /* MCU Configuration--------------------------------------------------------*/

  /* Reset of all peripherals, Initializes the Flash interface and the Systick. */
  HAL_Init();

  /* Configure the system clock */
  SystemClock_Config();

  /* USER CODE BEGIN SysInit */
  int TIM1_Ch1_DCVAL = 500;
  int TIM1_CH1_STEP = 20;
  /* USER CODE END SysInit */

  /* Initialize all configured peripherals */
  MX_GPIO_Init();
  MX_USART2_UART_Init();
  MX_ADC1_Init();
  MX_TIM1_Init();
  MX_TIM3_Init();
  MX_USART6_UART_Init();
  /* USER CODE BEGIN 2 */
  HAL_TIM_Base_Start(&htim1);
  HAL_TIM_PWM_Start(&htim1,TIM_CHANNEL_1);

  TIM1->PSC = 16-1;
  TIM1->ARR = 20000-1;
  TIM1->CCR1 = 00;

  clock_hours = 0;

//  uint8_t timer_ones = timer % 10;
//  uint8_t timer_tens = (timer - timer_ones) / 10;  // separate out digits A and B

  /* USER CODE END 2 */

  /* Infinite loop */
  /* USER CODE BEGIN WHILE */
//  HCSR04_TRIG_PULSE();
  TIM1->CCR1 = 2500;
  HAL_GPIO_WritePin(GPIOA, LD2_Pin, GPIO_PIN_RESET);

 // * SETUP CODE
  // Array to store inputs
    uint8_t setupInputs[17];
    char buffer[2] = {0};

    // Prompt and collect inputs
    sprintf((char*)txd_message_buffer, "\r SETUP MODE \n\n");
    HAL_UART_Transmit(&huart6, txd_message_buffer, strlen((char*)txd_message_buffer), HAL_MAX_DELAY);
    HAL_Delay(500);

    sprintf((char*)txd_message_buffer, "\r Enter SETUP Params \n\n");
    HAL_UART_Transmit(&huart6, txd_message_buffer, strlen((char*)txd_message_buffer), HAL_MAX_DELAY);

    sprintf((char*)txd_message_buffer, "\r\n Enter FIRST PIPELINE CHOICE FOR CONNECTION (0 for DEMO): ");
    HAL_UART_Transmit(&huart6, txd_message_buffer, strlen((char*)txd_message_buffer), HAL_MAX_DELAY);
    HAL_UART_Receive(&huart6, (uint8_t *)buffer, 1, HAL_MAX_DELAY);
    HAL_UART_Transmit(&huart6, (uint8_t *)buffer, 1, HAL_MAX_DELAY);
    setupInputs[0] = atoi(buffer);

    sprintf((char*)txd_message_buffer, "\r\n Enter FIRST PIPELINE CHOICE FOR MOTOR PWM (0 for DEMO): ");
    HAL_UART_Transmit(&huart6, txd_message_buffer, strlen((char*)txd_message_buffer), HAL_MAX_DELAY);
    HAL_UART_Receive(&huart6, (uint8_t *)buffer, 1, HAL_MAX_DELAY);
    HAL_UART_Transmit(&huart6, (uint8_t *)buffer, 1, HAL_MAX_DELAY);
    setupInputs[1] = atoi(buffer);

    sprintf((char*)txd_message_buffer, "\r\n Enter SECOND ZONE CHOICE FOR CONNECTION (1-3): ");
    HAL_UART_Transmit(&huart6, txd_message_buffer, strlen((char*)txd_message_buffer), HAL_MAX_DELAY);
    HAL_UART_Receive(&huart6, (uint8_t *)buffer, 1, HAL_MAX_DELAY);
    HAL_UART_Transmit(&huart6, (uint8_t *)buffer, 1, HAL_MAX_DELAY);
    setupInputs[2] = atoi(buffer);

    sprintf((char*)txd_message_buffer, "\r\n Enter SECOND ZONE CHOICE FOR MOTOR PWM (1-3): ");
    HAL_UART_Transmit(&huart6, txd_message_buffer, strlen((char*)txd_message_buffer), HAL_MAX_DELAY);
    HAL_UART_Receive(&huart6, (uint8_t *)buffer, 1, HAL_MAX_DELAY);
    HAL_UART_Transmit(&huart6, (uint8_t *)buffer, 1, HAL_MAX_DELAY);
    setupInputs[3] = atoi(buffer);

    sprintf((char*)txd_message_buffer, "\r\n Enter THIRD ZONE CHOICE FOR CONNECTION (1-3): ");
    HAL_UART_Transmit(&huart6, txd_message_buffer, strlen((char*)txd_message_buffer), HAL_MAX_DELAY);
    HAL_UART_Receive(&huart6, (uint8_t *)buffer, 1, HAL_MAX_DELAY);
    HAL_UART_Transmit(&huart6, (uint8_t *)buffer, 1, HAL_MAX_DELAY);
    setupInputs[4] = atoi(buffer);

    sprintf((char*)txd_message_buffer, "\r\n Enter THIRD ZONE CHOICE FOR MOTOR PWM (1-3): ");
    HAL_UART_Transmit(&huart6, txd_message_buffer, strlen((char*)txd_message_buffer), HAL_MAX_DELAY);
    HAL_UART_Receive(&huart6, (uint8_t *)buffer, 1, HAL_MAX_DELAY);
    HAL_UART_Transmit(&huart6, (uint8_t *)buffer, 1, HAL_MAX_DELAY);
    setupInputs[5] = atoi(buffer);

    sprintf((char*)txd_message_buffer, "\r\n Enter FORTH ZONE CHOICE FOR CONNECTION (1-3): ");
    HAL_UART_Transmit(&huart6, txd_message_buffer, strlen((char*)txd_message_buffer), HAL_MAX_DELAY);
    HAL_UART_Receive(&huart6, (uint8_t *)buffer, 1, HAL_MAX_DELAY);
    HAL_UART_Transmit(&huart6, (uint8_t *)buffer, 1, HAL_MAX_DELAY);
    setupInputs[6] = atoi(buffer);

    sprintf((char*)txd_message_buffer, "\r\n Enter FORTH ZONE CHOICE FOR MOTOR PWM (1-3): ");
    HAL_UART_Transmit(&huart6, txd_message_buffer, strlen((char*)txd_message_buffer), HAL_MAX_DELAY);
    HAL_UART_Receive(&huart6, (uint8_t *)buffer, 1, HAL_MAX_DELAY);
    HAL_UART_Transmit(&huart6, (uint8_t *)buffer, 1, HAL_MAX_DELAY);
    setupInputs[7] = atoi(buffer);

    sprintf((char*)txd_message_buffer, "\r\n Enter CURRENT WALL CLOCK TIME (00 for DEMO): ");
    HAL_UART_Transmit(&huart6, txd_message_buffer, strlen((char*)txd_message_buffer), HAL_MAX_DELAY);
    HAL_UART_Receive(&huart6, (uint8_t *)buffer, 2, HAL_MAX_DELAY);
    HAL_UART_Transmit(&huart6, (uint8_t *)buffer, 2, HAL_MAX_DELAY);
    setupInputs[8] = atoi(buffer);

    sprintf((char*)txd_message_buffer, "\r\n Enter INLET WALL CLOCK START TIME (00 for DEMO): ");
    HAL_UART_Transmit(&huart6, txd_message_buffer, strlen((char*)txd_message_buffer), HAL_MAX_DELAY);
    HAL_UART_Receive(&huart6, (uint8_t *)buffer, 2, HAL_MAX_DELAY);
    HAL_UART_Transmit(&huart6, (uint8_t *)buffer, 2, HAL_MAX_DELAY);
    setupInputs[9] = atoi(buffer);

    sprintf((char*)txd_message_buffer, "\r\n Enter INLET WALL CLOCK STOP TIME (07 for DEMO): ");
    HAL_UART_Transmit(&huart6, txd_message_buffer, strlen((char*)txd_message_buffer), HAL_MAX_DELAY);
    HAL_UART_Receive(&huart6, (uint8_t *)buffer, 2, HAL_MAX_DELAY);
    HAL_UART_Transmit(&huart6, (uint8_t *)buffer, 2, HAL_MAX_DELAY);
    setupInputs[10] = atoi(buffer);

    sprintf((char*)txd_message_buffer, "\r\n Enter FIRST ZONE CHOICE WALL CLOCK START TIME (08-23): ");
    HAL_UART_Transmit(&huart6, txd_message_buffer, strlen((char*)txd_message_buffer), HAL_MAX_DELAY);
    HAL_UART_Receive(&huart6, (uint8_t *)buffer, 2, HAL_MAX_DELAY);
    HAL_UART_Transmit(&huart6, (uint8_t *)buffer, 2, HAL_MAX_DELAY);
    setupInputs[11] = atoi(buffer);

    sprintf((char*)txd_message_buffer, "\r\n Enter FIRST ZONE CHOICE WALL CLOCK STOP TIME (09-23): ");
    HAL_UART_Transmit(&huart6, txd_message_buffer, strlen((char*)txd_message_buffer), HAL_MAX_DELAY);
    HAL_UART_Receive(&huart6, (uint8_t *)buffer, 2, HAL_MAX_DELAY);
    HAL_UART_Transmit(&huart6, (uint8_t *)buffer, 2, HAL_MAX_DELAY);
    setupInputs[12] = atoi(buffer);

    sprintf((char*)txd_message_buffer, "\r\n Enter SECOND ZONE CHOICE WALL CLOCK START TIME (08-23): ");
    HAL_UART_Transmit(&huart6, txd_message_buffer, strlen((char*)txd_message_buffer), HAL_MAX_DELAY);
    HAL_UART_Receive(&huart6, (uint8_t *)buffer, 2, HAL_MAX_DELAY);
    HAL_UART_Transmit(&huart6, (uint8_t *)buffer, 2, HAL_MAX_DELAY);
    setupInputs[13] = atoi(buffer);

    sprintf((char*)txd_message_buffer, "\r\n Enter SECOND ZONE CHOICE WALL CLOCK STOP TIME (09-23): ");
    HAL_UART_Transmit(&huart6, txd_message_buffer, strlen((char*)txd_message_buffer), HAL_MAX_DELAY);
    HAL_UART_Receive(&huart6, (uint8_t *)buffer, 2, HAL_MAX_DELAY);
    HAL_UART_Transmit(&huart6, (uint8_t *)buffer, 2, HAL_MAX_DELAY);
    setupInputs[14] = atoi(buffer);

    sprintf((char*)txd_message_buffer, "\r\n Enter THIRD ZONE CHOICE WALL CLOCK START TIME (08-23): ");
    HAL_UART_Transmit(&huart6, txd_message_buffer, strlen((char*)txd_message_buffer), HAL_MAX_DELAY);
    HAL_UART_Receive(&huart6, (uint8_t *)buffer, 2, HAL_MAX_DELAY);
    HAL_UART_Transmit(&huart6, (uint8_t *)buffer, 2, HAL_MAX_DELAY);
    setupInputs[15] = atoi(buffer);

    sprintf((char*)txd_message_buffer, "\r\n Enter THIRD ZONE CHOICE WALL CLOCK STOP TIME (09-23): ");
    HAL_UART_Transmit(&huart6, txd_message_buffer, strlen((char*)txd_message_buffer), HAL_MAX_DELAY);
    HAL_UART_Receive(&huart6, (uint8_t *)buffer, 2, HAL_MAX_DELAY);
    HAL_UART_Transmit(&huart6, (uint8_t *)buffer, 2, HAL_MAX_DELAY);
    setupInputs[16] = atoi(buffer);

    sprintf((char*)txd_message_buffer, "\r\n\n Printing Set Up Parameters \n");
    HAL_UART_Transmit(&huart6, txd_message_buffer, strlen((char*)txd_message_buffer), HAL_MAX_DELAY);

    sprintf((char*)txd_message_buffer, "\r\n FIRST PIPELINE CHOICE: 0 \t");
    HAL_UART_Transmit(&huart6, txd_message_buffer, strlen((char*)txd_message_buffer), HAL_MAX_DELAY);
    sprintf((char*)txd_message_buffer, "Pump PWR: %d\t", setupInputs[1]);
    HAL_UART_Transmit(&huart6, txd_message_buffer, strlen((char*)txd_message_buffer), HAL_MAX_DELAY);
    sprintf((char*)txd_message_buffer, "FIRST ZONE CHOICE WALL CLOCK START TIME: %d\t", setupInputs[11]);
    HAL_UART_Transmit(&huart6, txd_message_buffer, strlen((char*)txd_message_buffer), HAL_MAX_DELAY);
    sprintf((char*)txd_message_buffer, "FIRST ZONE CHOICE WALL CLOCK STOP TIME: %d\t", setupInputs[12]);
    HAL_UART_Transmit(&huart6, txd_message_buffer, strlen((char*)txd_message_buffer), HAL_MAX_DELAY);

    sprintf((char*)txd_message_buffer, "\r\n SECOND ZONE CHOICE: %d \t", setupInputs[2]);
    HAL_UART_Transmit(&huart6, txd_message_buffer, strlen((char*)txd_message_buffer), HAL_MAX_DELAY);
    sprintf((char*)txd_message_buffer, "Pump PWR: %d\t", setupInputs[3]);
    HAL_UART_Transmit(&huart6, txd_message_buffer, strlen((char*)txd_message_buffer), HAL_MAX_DELAY);
    sprintf((char*)txd_message_buffer, "SECOND ZONE CHOICE WALL CLOCK START TIME: %d\t", setupInputs[13]);
    HAL_UART_Transmit(&huart6, txd_message_buffer, strlen((char*)txd_message_buffer), HAL_MAX_DELAY);
    sprintf((char*)txd_message_buffer, "SECOND ZONE CHOICE WALL CLOCK STOP TIME: %d\t", setupInputs[14]);
    HAL_UART_Transmit(&huart6, txd_message_buffer, strlen((char*)txd_message_buffer), HAL_MAX_DELAY);

    sprintf((char*)txd_message_buffer, "\r\n THIRD ZONE CHOICE: %d \t", setupInputs[4]);
    HAL_UART_Transmit(&huart6, txd_message_buffer, strlen((char*)txd_message_buffer), HAL_MAX_DELAY);
    sprintf((char*)txd_message_buffer, "Pump PWR: %d\t", setupInputs[5]);
    HAL_UART_Transmit(&huart6, txd_message_buffer, strlen((char*)txd_message_buffer), HAL_MAX_DELAY);
    sprintf((char*)txd_message_buffer, "THIRD ZONE CHOICE WALL CLOCK START TIME: %d\t", setupInputs[15]);
    HAL_UART_Transmit(&huart6, txd_message_buffer, strlen((char*)txd_message_buffer), HAL_MAX_DELAY);
    sprintf((char*)txd_message_buffer, "THIRD ZONE CHOICE WALL CLOCK STOP TIME: %d\t", setupInputs[16]);
    HAL_UART_Transmit(&huart6, txd_message_buffer, strlen((char*)txd_message_buffer), HAL_MAX_DELAY);

    uint8_t percent_full = 0;

	  sprintf((char*)txd_message_buffer, "\r\n\n SETUP is done. Press BLUE BUTTON for RUN MODE. ");
	  HAL_UART_Transmit(&huart6, txd_message_buffer, strlen((char*)txd_message_buffer), HAL_MAX_DELAY);
	  while(HAL_GPIO_ReadPin(GPIOC, GPIO_PIN_13) == 1){
		  HAL_GPIO_WritePin(GPIOA, LD2_Pin, GPIO_PIN_SET);
		  HAL_Delay(50);
		  HAL_GPIO_WritePin(GPIOA, LD2_Pin, GPIO_PIN_RESET);
		  HAL_Delay(50);
		  if (HAL_GPIO_ReadPin(GPIOC, GPIO_PIN_13) == 0){
			  break;
		  }
	  }

	  HAL_GPIO_WritePin(GPIOA, LD2_Pin, GPIO_PIN_SET);
	  sprintf((char*)txd_message_buffer, "\r\n\n RUN MODE \n\n");
	  HAL_UART_Transmit(&huart6, txd_message_buffer, strlen((char*)txd_message_buffer), HAL_MAX_DELAY);

  // RUN MODE CODE WITH TITLES

	  sprintf((char*)txd_message_buffer, "\r WALL CLOCK (hr): | ZONE/INLET: | MOTOR %%PWM: | RPM: | WATER DEPTH (%%): \n");
	  HAL_UART_Transmit(&huart6, txd_message_buffer, strlen((char*)txd_message_buffer), HAL_MAX_DELAY);

	  HAL_TIM_Base_Init(&htim3);
	  HAL_TIM_PWM_Start(&htim3, TIM_CHANNEL_1);
	  HAL_TIM_PWM_Start(&htim3, TIM_CHANNEL_2);

	  uint8_t PWM_Percent = 0;

	  for (int i = 0; i <= 24; i++){
		  uint8_t zone_number = 100;
		  if (i >= 0 && i < 7){
			  zone_number = 0;
			  HAL_GPIO_WritePin(GPIOB, BLUE_Pin, 0);
			  HAL_GPIO_WritePin(GPIOB, RED_Pin, 0);
			  HAL_GPIO_WritePin(GPIOA, GREEN_Pin, 0);

			  HAL_GPIO_WritePin(GPIOB, BLUE_Pin, 1);
			  HAL_GPIO_WritePin(GPIOA, RED_Pin, 1);

			  HAL_TIM_Base_Start(&htim1);
			  HAL_TIM_PWM_Start(&htim1,TIM_CHANNEL_1);
			  TIM1->PSC = 16-1;
			  TIM1->ARR = 20000-1;
			  TIM1->CCR1 = 2500;

			  /*
			   * NOTE: since we set the PWM to be 0 in this case, we should be able to adjust the value of the Motor Speed using the potentiometer
			   */

		  } else if (i >= 7 && i < setupInputs[12]){
			  zone_number = 1;
			  HAL_GPIO_WritePin(GPIOB, BLUE_Pin, 0);
			  HAL_GPIO_WritePin(GPIOB, RED_Pin, 0);
			  HAL_GPIO_WritePin(GPIOA, GREEN_Pin, 0);

			  HAL_GPIO_WritePin(GPIOA, RED_Pin, 1);

			  HAL_TIM_Base_Start(&htim1);
			  HAL_TIM_PWM_Start(&htim1,TIM_CHANNEL_1);
			  TIM1->PSC = 16-1;
			  TIM1->ARR = 20000-1;
			  TIM1->CCR1 = 1834;

			  if (setupInputs[3] == 1){
				  PWM_Percent = 70;
			  } else if (setupInputs[3] == 2){
				  PWM_Percent = 85;
			  } else if (setupInputs[3] == 3){
				  PWM_Percent = 90;
			  }

		  } else if (i >= setupInputs[12] && i < setupInputs[14]){
			  zone_number = 2;
			  HAL_GPIO_WritePin(GPIOB, BLUE_Pin, 0);
			  HAL_GPIO_WritePin(GPIOB, RED_Pin, 0);
			  HAL_GPIO_WritePin(GPIOA, GREEN_Pin, 0);

			  HAL_GPIO_WritePin(GPIOA, GREEN_Pin, 1);

			  HAL_TIM_Base_Start(&htim1);
			  HAL_TIM_PWM_Start(&htim1,TIM_CHANNEL_1);
			  TIM1->PSC = 16-1;
			  TIM1->ARR = 20000-1;
			  TIM1->CCR1 = 1168;

			  if (setupInputs[5] == 1){
				  PWM_Percent = 70;
			  } else if (setupInputs[5] == 2){
				  PWM_Percent = 85;
			  } else if (setupInputs[5] == 3){
				  PWM_Percent = 90;
			  }

		  } else if (i >= setupInputs[14] && i < setupInputs[16]){
			  zone_number = 3;
			  HAL_GPIO_WritePin(GPIOB, BLUE_Pin, 0);
			  HAL_GPIO_WritePin(GPIOB, RED_Pin, 0);
			  HAL_GPIO_WritePin(GPIOA, GREEN_Pin, 0);

			  HAL_GPIO_WritePin(GPIOB, BLUE_Pin, 1);
			  HAL_TIM_Base_Start(&htim1);
			  HAL_TIM_PWM_Start(&htim1,TIM_CHANNEL_1);
			  TIM1->PSC = 16-1;
			  TIM1->ARR = 20000-1;
			  TIM1->CCR1 = 500;

			  if (setupInputs[7] == 1){
				  PWM_Percent = 70;
			  } else if (setupInputs[7] == 2){
				  PWM_Percent = 85;
			  } else if (setupInputs[7] == 3){
				  PWM_Percent = 90;
			  }



		  } else if (i >= setupInputs[16]){
			  sprintf((char*)txd_message_buffer, "\r %d| %s| %d| %d| %d\n", i, " " ,PWM_Percent, rpm_tick_count, percent_full);
			  HAL_UART_Transmit(&huart6, txd_message_buffer, strlen((char*)txd_message_buffer), HAL_MAX_DELAY);
			  PWM_Percent = 0;

			  HAL_GPIO_WritePin(GPIOB, BLUE_Pin, GPIO_PIN_RESET);
			  HAL_GPIO_WritePin(GPIOB, RED_Pin, GPIO_PIN_RESET);
			  HAL_GPIO_WritePin(GPIOA, GREEN_Pin, GPIO_PIN_RESET);

			  if (i == 24){
				  sprintf((char*)txd_message_buffer, "Irrigation Complete\r\n");
				  HAL_UART_Transmit(&huart6, txd_message_buffer, strlen((char*)txd_message_buffer), HAL_MAX_DELAY);
				  break;
			  }
			  HAL_Delay(12000);
		  }



		  // Getting the distance from sensor
//		  hcsr04_Rx_flag = 0;
//		  first_edge = 0;
//		  time_edge1 = 0;
//		  time_edge2 = 0;
//		  time_diff = 0;
//		  distance = 0;
//		  max_depth = 100;
//
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

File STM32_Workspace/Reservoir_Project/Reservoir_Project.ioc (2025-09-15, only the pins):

Mcu.UserName=STM32F411RETx
PA0-WKUP.GPIO_Label=DIGIT_A3
PA0-WKUP.Signal=GPIO_Output
PA1.GPIO_Label=DIGIT_A2
PA1.Signal=GPIO_Output
PA10.GPIO_Label=DIGIT_B2
PA10.Signal=GPXTI10
PA11.GPIO_Label=GREEN
PA11.Signal=GPIO_Output
PA12.GPIO_Label=RED
PA12.Signal=GPIO_Output
PA13.GPIO_Label=TMS
PA13.Signal=SYS_JTMS-SWDIO
PA14.GPIO_Label=TCK
PA14.Signal=SYS_JTCK-SWCLK
PA2.GPIO_Label=USART_TX
PA2.Signal=USART2_TX
PA3.GPIO_Label=USART_RX
PA3.Signal=USART2_RX
PA4.GPIO_Label=DIGIT_A1
PA4.Signal=GPIO_Output
PA5.GPIO_Label=LD2 [Green Led]
PA5.Signal=GPIO_Output
PA8.Signal=S_TIM1_CH1
PB0.GPIO_Label=DIGIT_A0
PB0.Signal=GPIO_Output
PB1.Signal=ADCx_IN9
PB12.GPIO_Label=DIGIT_B0
PB12.Signal=GPIO_Output
PB14.GPIO_Label=DIGIT_B1
PB14.Signal=GPIO_Output
PB15.GPIO_Label=BLUE
PB15.Signal=GPIO_Output
PB2.GPIO_Label=RPM_TICK
PB2.Signal=GPXTI2
PB3.GPIO_Label=SWO
PB3.Signal=SYS_JTDO-SWO
PB4.Signal=S_TIM3_CH1
PB5.Signal=S_TIM3_CH2
PC0.GPIO_Label=TRIG_PIN
PC0.Signal=GPIO_Input
PC1.GPIO_Label=DIGIT_B3
PC1.Signal=GPIO_Output
PC13-ANTI_TAMP.Signal=GPIO_Input
PC14-OSC32_IN.Signal=RCC_OSC32_IN
PC15-OSC32_OUT.Signal=RCC_OSC32_OUT
PC6.Signal=USART6_TX
PC7.Signal=USART6_RX

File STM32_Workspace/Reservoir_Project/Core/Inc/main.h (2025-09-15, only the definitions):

#define TRIG_PIN_Pin GPIO_PIN_0
#define TRIG_PIN_GPIO_Port GPIOC
#define DIGIT_B3_Pin GPIO_PIN_1
#define DIGIT_B3_GPIO_Port GPIOC
#define DIGIT_A3_Pin GPIO_PIN_0
#define DIGIT_A3_GPIO_Port GPIOA
#define DIGIT_A2_Pin GPIO_PIN_1
#define DIGIT_A2_GPIO_Port GPIOA
#define USART_TX_Pin GPIO_PIN_2
#define USART_TX_GPIO_Port GPIOA
#define USART_RX_Pin GPIO_PIN_3
#define USART_RX_GPIO_Port GPIOA
#define DIGIT_A1_Pin GPIO_PIN_4
#define DIGIT_A1_GPIO_Port GPIOA
#define LD2_Pin GPIO_PIN_5
#define LD2_GPIO_Port GPIOA
#define DIGIT_A0_Pin GPIO_PIN_0
#define DIGIT_A0_GPIO_Port GPIOB
#define RPM_TICK_Pin GPIO_PIN_2
#define RPM_TICK_GPIO_Port GPIOB
#define RPM_TICK_EXTI_IRQn EXTI2_IRQn
#define DIGIT_B0_Pin GPIO_PIN_12
#define DIGIT_B0_GPIO_Port GPIOB
#define DIGIT_B1_Pin GPIO_PIN_14
#define DIGIT_B1_GPIO_Port GPIOB
#define BLUE_Pin GPIO_PIN_15
#define BLUE_GPIO_Port GPIOB
#define DIGIT_B2_Pin GPIO_PIN_10
#define DIGIT_B2_GPIO_Port GPIOA
#define GREEN_Pin GPIO_PIN_11
#define GREEN_GPIO_Port GPIOA
#define RED_Pin GPIO_PIN_12
#define RED_GPIO_Port GPIOA
#define TMS_Pin GPIO_PIN_13
#define TMS_GPIO_Port GPIOA
#define TCK_Pin GPIO_PIN_14
#define TCK_GPIO_Port GPIOA
#define SWO_Pin GPIO_PIN_3
#define SWO_GPIO_Port GPIOB

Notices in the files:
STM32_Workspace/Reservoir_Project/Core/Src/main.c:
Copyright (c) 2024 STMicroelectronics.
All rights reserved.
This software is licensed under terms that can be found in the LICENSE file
